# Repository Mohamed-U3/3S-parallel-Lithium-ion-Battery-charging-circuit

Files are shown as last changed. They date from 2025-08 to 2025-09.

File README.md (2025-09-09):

# U3 LiPo Charging Circuit

A complete modular LiPo battery management solution, designed in KiCad by Eng. Mohamed Yousry. This project combines a charger, protection circuit, and active balancer for safe and efficient LiPo battery management, suited for embedded systems, robotics, and DIY electronics.

***

## Features

- **Battery Charging Circuit**
    - **IC:** BQ24090DGQ
    - Input: 5V (USB or external)
    - Integrated current setting, termination, and charging indicators
    - Optimized for single-cell LiPo batteries
- **Battery Protection Circuit**
    - **IC:** XB8889D
    - Overcharge, overdischarge, and short-circuit protection
    - Automatic recovery feature
    - Output and input connectors included for seamless integration
- **Active Balancer Circuit**
    - Balance two battery cells using autonomous active balancer ICs
    - **Inductor-based charge redistribution** for improved battery health
    - Independent status and enable pins for customization

***

## Schematic Overview

The project schematic is divided into three main sections:

1. **Battery Charging Circuit** – Handles safe charging of the LiPo cell.
2. **Battery Protection Circuit** – Protects against voltage and current faults.
3. **Active Balancer Circuit** – Maintains consistent voltage across multi-cell packs.

_All schematic design is done in KiCad 6.0 and up._

***

## Getting Started

### Prerequisites

- **KiCad** version 6.0+ (required to open Design Files)
- Basic electronics assembly and soldering skills

### Files Included

- `LiPoCharger.kicad_sch`: Complete project schematic
- (You may add: BOM, Gerber files, and 3D models if available)

### How to Use

1. **Review the schematic file** (`.kicad_sch`) in KiCad.
2. Modify component values as needed for your specific battery and current specs.
3. Generate PCB layout and fabricate your board.
4. Solder components according to schematic.
5. Integrate into your battery-powered project.

***

## Block Diagram

```
[5V Charger Input] --> [Charging Circuit] --> [Protection Circuit] --> [Active Balancer] --> [Battery Pack]
```

***

## License

This project is open-source and licensed under the MIT License. See `LICENSE` file for details.

***

## Author

**Eng. Mohamed Yousry**
Mechatronics Engineer / Embedded Hardware \& Software Designer

***

## Contribution \& Support

- Issues and pull requests are welcome!
- For questions or collaboration: mohamed.yousry0023@gmail.com

***

## Acknowledgements

- Designed using KiCad EDA 9.0.3
- Inspired by robust battery management requirements in embedded applications
- Inspired by GreatScott! Youtube channel

***

> **Disclaimer:** Double-check all component ratings for your specific application. Improper LiPo charging/protection can be dangerous.

---
<span style="display:none">[^1]</span>

<div style="text-align: center">⁂</div>

[^1]: image.jpeg

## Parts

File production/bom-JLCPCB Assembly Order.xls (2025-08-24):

JLCPCB BOM Tool - BOM Matching
BOM name：bom-JLCPCB Assembly Order-JLCPCB Assembly Order.xlsx |  |  | Download Time：2025-08-14 16:01:05 |  |  |  | * Our matching results are updated in real-time, but stock and prices may change. If it's been over 24 hours, please re-match before placing your order.
PCB Assembled Qty：5 |  |  | Est. Total Price：10.3532
Your BOM |  |  |  |  | Matched Parts |  |  |  |  |  |  | Order Information
Top Designator | Bottom Designator | Comment | Footprint | JLCPCB Part # | Matches | Part # | Manufacturer | Footprint | Description | Category | Warning | JLCPCB Part # | Product link | Lib Type | Qty | Source | Total Price ($)
C1,C10,C11,C2,C3,C6,C7 |  | 10uF | 0402 |  | Select by System | CL05A106MQ5NUNC | Samsung Electro-Mechanics | 0402 | 10uF 6.3V X5R ±20% 0402 Multilayer Ceramic Capacitors MLCC - SMD/SMT ROHS | Multilayer Ceramic Capacitors MLCC - SMD/SMT |  | C15525 | https://jlcpcb.com/partdetail/16204-CL05A106MQ5NUNC/C15525 | Basic | 45 | 45 JLCPCB | 0.2655
C4,C8 |  | 1nF | 0402 |  | Select by System | 0402B102K500NT | FH (Guangdong Fenghua Advanced Tech) | 0402 | 1nF 50V X7R ±10% 0402 Multilayer Ceramic Capacitors MLCC - SMD/SMT ROHS | Multilayer Ceramic Capacitors MLCC - SMD/SMT |  | C1523 | https://jlcpcb.com/partdetail/1875-0402B102K500NT/C1523 | Basic | 20 | 20 JLCPCB | 0.022
C5,C9 |  | 10nF | 0402 |  | Select by System | CL05B103KB5NNNC | Samsung Electro-Mechanics | 0402 | 10nF 50V X7R ±10% 0402 Multilayer Ceramic Capacitors MLCC - SMD/SMT ROHS | Multilayer Ceramic Capacitors MLCC - SMD/SMT |  | C15195 | https://jlcpcb.com/partdetail/15869-CL05B103KB5NNNC/C15195 | Basic | 20 | 20 JLCPCB | 0.026
D1,D3,D4 |  | Red | 0603 |  | Select by System | KT-0603R | Hubei KENTO Elec | 0603 | -40℃~+85℃ Red 0603 LED Indication - Discrete ROHS | LED Indication - Discrete |  | C2286 | https://jlcpcb.com/partdetail/Hubei_KENTOElec-KT0603R/C2286 | Basic | 25 | 25 JLCPCB | 0.14
D2 |  | Green | 0603 |  | Select by System | F.0603.00025/P2-0603G1TS2-06T-002 | TUOZHAN | 0603 | -40℃~+85℃ 120° 2.6V~2.9V 230mcd 520nm~525nm Emerald Green 0603 LED Indication - Discrete ROHS | LED Indication - Discrete |  | C7496818 | https://jlcpcb.com/partdetail/C7496818 | Extended | 20 | 20 JLCPCB | 0.062
J1 |  | Battery_conn_in | 插件,P=2mm |  | Unconfirmed | B2B-PH-K-S(LF)(SN) | JST | 插件,P=2mm | -25℃~+85℃ 1 100V 1x2P 2 2A 2P 2mm 4.5mm 5.9mm 6mm Brass K Pin PA66 PH Through Hole Tin UL94V-0 White Plugin,P=2mm Wire To Board Connector ROHS | Wire To Board Connector | 1.Multiple lines in the BOM have been matched to the same part. Please check if the matching is correct. ; | C131337 | https://jlcpcb.com/partdetail/JST-B2B_PH_K_S_LF_SN/C131337 | Extended | 16 | 16 JLCPCB | 0.4896
J2 |  | Battery_conn_out | 插件,P=2mm |  | Unconfirmed | B2B-PH-K-S(LF)(SN) | JST | 插件,P=2mm | -25℃~+85℃ 1 100V 1x2P 2 2A 2P 2mm 4.5mm 5.9mm 6mm Brass K Pin PA66 PH Through Hole Tin UL94V-0 White Plugin,P=2mm Wire To Board Connector ROHS | Wire To Board Connector | 1.Multiple lines in the BOM have been matched to the same part. Please check if the matching is correct. ; | C131337 | https://jlcpcb.com/partdetail/JST-B2B_PH_K_S_LF_SN/C131337 | Extended | 16 | 16 JLCPCB | 0.4896
J3 |  | Charger_conn | 插件,P=2mm |  | Unconfirmed | B2B-PH-K-S(LF)(SN) | JST | 插件,P=2mm | -25℃~+85℃ 1 100V 1x2P 2 2A 2P 2mm 4.5mm 5.9mm 6mm Brass K Pin PA66 PH Through Hole Tin UL94V-0 White Plugin,P=2mm Wire To Board Connector ROHS | Wire To Board Connector | 1.Multiple lines in the BOM have been matched to the same part. Please check if the matching is correct. ; | C131337 | https://jlcpcb.com/partdetail/JST-B2B_PH_K_S_LF_SN/C131337 | Extended | 16 | 16 JLCPCB | 0.4896
J4 |  | Conn_01x04_batteries | 插件,P=2.5mm |  | Select by System | B4B-EH-A(LF)(SN) | JST | 插件,P=2.5mm | -25℃~+85℃ 1 12.5mm 1x4P 2.5mm 250V 3.8mm 3A 4 4P 6mm Brass EH K Pin PA66 Through Hole Tin UL94V-0 White Plugin,P=2.5mm Wire To Board Connector ROHS | Wire To Board Connector |  | C160258 | https://jlcpcb.com/partdetail/JST-B4B_EH_A_LF_SN/C160258 | Extended | 5 | 5 JLCPCB | 0.2545
L1,L2 |  | 1uH | SMD,3x3mm |  | Select by System | SWPA3010S1R0NT | Sunlord | SMD,3x3mm | 1.4A 1.4A 1uH 85mΩ ±30% SMD,3x3mm Power Inductors ROHS | Power Inductors |  | C57625 | https://jlcpcb.com/partdetail/Sunlord-SWPA3010S1R0NT/C57625 | Extended | 14 | 14 JLCPCB | 0.8022
R1,R6 |  | 1k | 0201 |  | Select by System | 0201WMF1001TEE | UNI-ROYAL(Uniroyal Elec) | 0201 | -55℃~+155℃ 1kΩ 25V 50mW Thick Film Resistor ±1% ±200ppm/℃ 0201 Chip Resistor - Surface Mount ROHS | Chip Resistor - Surface Mount |  | C270365 | https://jlcpcb.com/partdetail/259895-0201WMF1001TEE/C270365 | Extended | 22 | 22 JLCPCB | 0.0132
R2 |  | 536R | 0201 |  | Select by System | RTT015360FTH | RALEC | 0201 | -55℃~+125℃ 25V 50mW 536Ω Thick Film Resistor ±1% ±200ppm/℃ 0201 Chip Resistor - Surface Mount ROHS | Chip Resistor - Surface Mount |  | C166162 | https://jlcpcb.com/partdetail/RALEC-RTT015360FTH/C166162 | Extended | 20 | 20 JLCPCB | 0.042
R3 |  | 10k | 0201 |  | Select by System | 0201WMF1002TEE | UNI-ROYAL(Uniroyal Elec) | 0201 | -55℃~+155℃ 10kΩ 25V 50mW Thick Film Resistor ±1% ±200ppm/℃ 0201 Chip Resistor - Surface Mount ROHS | Chip Resistor - Surface Mount |  | C473048 | https://jlcpcb.com/partdetail/479818-0201WMF1002TEE/C473048 | Extended | 20 | 20 JLCPCB | 0.012
R4,R5,R7,R9 |  | 1k5 | 0201 |  | Select by System | RC0201FR-071K5L | YAGEO | 0201 | -55℃~+125℃ 1.5kΩ 25V 50mW Thick Film Resistor ±1% ±200ppm/℃ 0201 Chip Resistor - Surface Mount ROHS | Chip Resistor - Surface Mount |  | C155737 | https://jlcpcb.com/partdetail/YAGEO-RC0201FR071K5L/C155737 | Extended | 30 | 30 JLCPCB | 0.024
R10,R8 |  | 51K | 0201 |  | Select by System | 0201WMF5102TEE | UNI-ROYAL(Uniroyal Elec) | 0201 | -55℃~+155℃ 25V 50mW 51kΩ Thick Film Resistor ±1% ±200ppm/℃ 0201 Chip Resistor - Surface Mount ROHS | Chip Resistor - Surface Mount |  | C473471 | https://jlcpcb.com/partdetail/479864-0201WMF5102TEE/C473471 | Extended | 20 | 20 JLCPCB | 0.014
U1 |  | BQ24090DGQ | HVSSOP-10-EP-0.5mm |  | Select by System | BQ24090DGQT | Texas Instruments | HVSSOP-10-EP-0.5mm | 0℃~+125℃ 1 125uA 1A 4.2V 4.45V~6.45V Charging IC Lithium Battery Support Support HVSSOP-10-EP-0.5mm Battery Management ROHS | Battery Management |  | C2879218 | https://jlcpcb.com/partdetail/TexasInstruments-BQ24090DGQT/C2879218 | Extended | 5 | 5 JLCPCB | 3.33
U2 |  | XB8089D | SOIC-8-EP |  | Select by System | XB8089D | XySemi | SOIC-8-EP | -40℃~+85℃ 1 2.5V 4.25V Lithium-ion/Polymer SOIC-8-EP Battery Management ROHS | Battery Management |  | C79928 | https://jlcpcb.com/partdetail/XySemi-XB8089D/C79928 | Extended | 5 | 5 JLCPCB | 0.757
U3,U4 |  | ETA3000 | DFN2x2-8 |  | Select by System | ETA3000D2I | etasolution | DFN2x2-8 | -40℃~+85℃ 2 2A 3.75V~12V Battery Balancing IC Lithium-ion/Polymer DFN2x2-8 Battery Management ROHS | Battery Management |  | C7465544 | https://jlcpcb.com/partdetail/etasolution-ETA3000D2I/C7465544 | Extended | 10 | 10 JLCPCB | 3.12
MOUSE-BITE-2MM-SLOT_2,MOUSE-BITE-2MM-SLOT |  | VAL** |  |  | No matches | No Part Selected

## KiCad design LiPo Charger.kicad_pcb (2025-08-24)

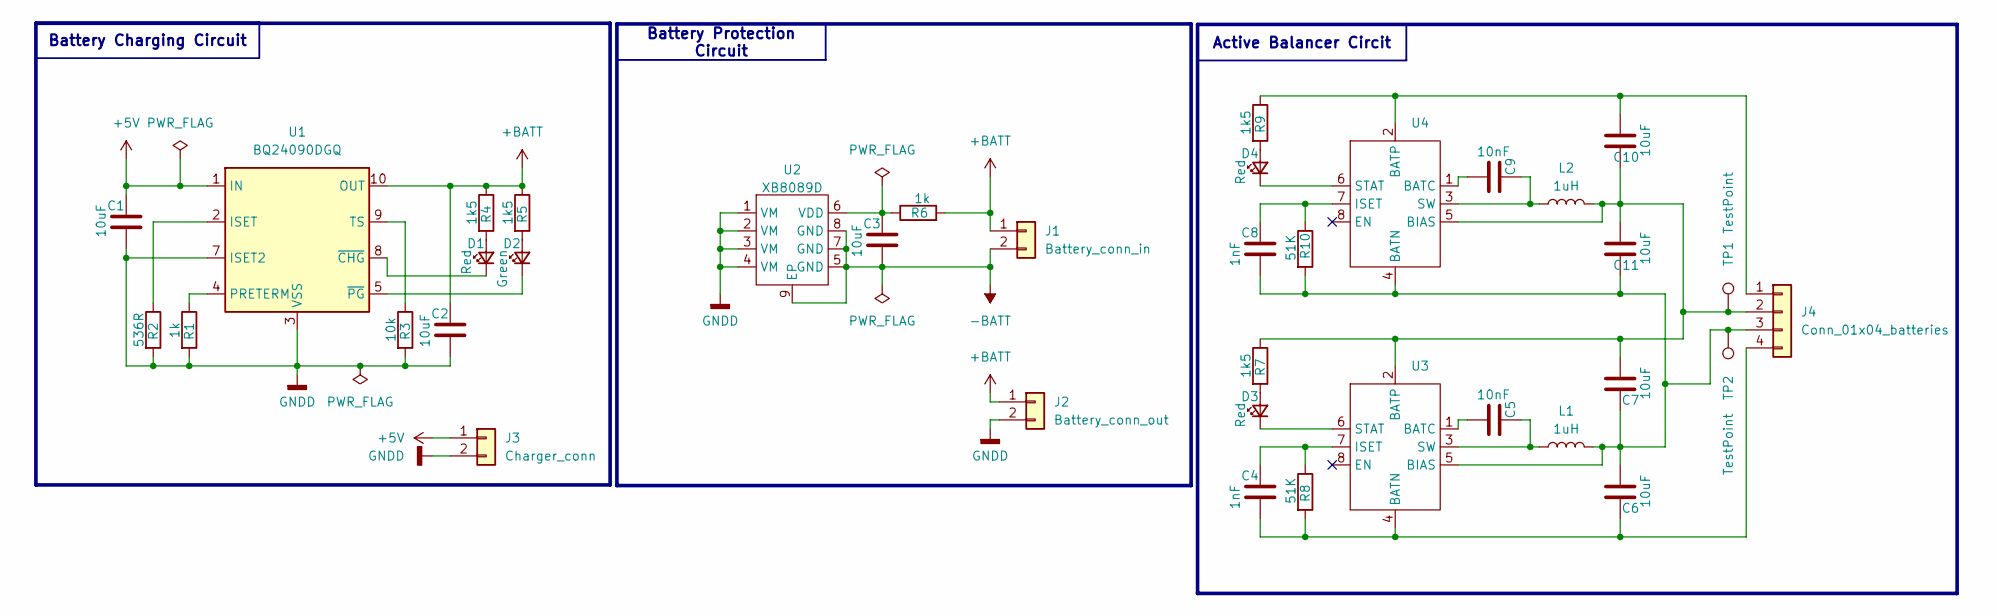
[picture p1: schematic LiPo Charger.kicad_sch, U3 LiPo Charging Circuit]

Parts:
C1, C2, C3, C6, C7, C10, C11: 10uF; C_0402_1005Metric_Pad0.74x0.62mm_HandSolder
C4, C8: 1nF; C_0402_1005Metric_Pad0.74x0.62mm_HandSolder
C5, C9: 10nF; C_0402_1005Metric_Pad0.74x0.62mm_HandSolder
D1, D3, D4: Red; LED_0603_1608Metric_Red
D2: Green; LED_0603_1608Metric_Green
J1: Battery_conn_in; JST_PH_B2B-PH-K_1x02_P2.00mm_Vertical
J2: Battery_conn_out; JST_PH_B2B-PH-K_1x02_P2.00mm_Vertical
J3: Charger_conn; JST_PH_B2B-PH-K_1x02_P2.00mm_Vertical
J4: Conn_01x04_batteries; JST_EH_B4B-EH-A_1x04_P2.50mm_Vertical
L1, L2: 1uH; L_Sunlord_SWPA3010S
R1, R6: 1k; R_0201_0603Metric_Pad0.64x0.40mm_HandSolder
R2: 536R; R_0201_0603Metric_Pad0.64x0.40mm_HandSolder
R3: 10k; R_0201_0603Metric_Pad0.64x0.40mm_HandSolder
R4, R5, R7, R9: 1k5; R_0201_0603Metric_Pad0.64x0.40mm_HandSolder
R8, R10: 51K; R_0201_0603Metric_Pad0.64x0.40mm_HandSolder
TP1, TP2: TestPoint; TestPoint_Pad_D1.5mm
U1: BQ24090DGQ; HVSSOP-10-1EP_3x3mm_P0.5mm_EP1.57x1.88mm_ThermalVias
U2: XB8089D; HTSOP-8-1EP_3.9x4.9mm_P1.27mm_EP2.4x3.2mm_ThermalVias
U3, U4: ETA3000; DFN-8-1EP_2x2mm_P0.5mm_EP0.6x1.2mm

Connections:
+5V: C1.1, J3.1, U1.1 (IN)
+BATT: C2.1, J1.1, J2.1, R4.1, R5.1, R6.2, U1.10 (OUT)
-BATT: C3.2, J1.2, U2.5 (GND), U2.7 (GND), U2.8 (GND), U2.9 (EP)
GNDD: C1.2, C2.2, J2.2, J3.2, R1.2, R2.2, R3.2, U1.3 (VSS), U1.7 (ISET2), U1.11 (VSS), U2.1 (VM), U2.2 (VM), U2.3 (VM), U2.4 (VM)
unnamed: D1.2 (A), R4.2
unnamed: D1.1 (K), U1.8 (~CHG)
unnamed: D2.2 (A), R5.2
unnamed: D2.1 (K), U1.5 (~PG)
unnamed: D3.2 (A), R7.2
unnamed: D3.1 (K), U3.6 (STAT)
unnamed: D4.2 (A), R9.2
unnamed: D4.1 (K), U4.6 (STAT)
unnamed: C10.2, J4.1, R9.1, U4.2 (BATP)
unnamed: C7.2, C10.1, C11.2, J4.2, L2.2, R7.1, TP1.1, U3.2 (BATP), U4.5 (BIAS)
unnamed: C6.2, C7.1, C8.2, C11.1, J4.3, L1.2, R10.2, TP2.1, U3.5 (BIAS), U4.4 (BATN)
unnamed: C4.2, C6.1, J4.4, R8.2, U3.4 (BATN)
unnamed: R2.1, U1.2 (ISET)
unnamed: R1.1, U1.4 (PRETERM)
unnamed: R3.1, U1.9 (TS)
unnamed: C3.1, R6.1, U2.6 (VDD)
unnamed: C5.2, U3.1 (BATC)
unnamed: C4.1, R8.1, U3.7 (ISET)
unnamed: C5.1, L1.1, U3.3 (SW)
unnamed: C9.2, U4.1 (BATC)
unnamed: C8.1, R10.1, U4.7 (ISET)
unnamed: C9.1, L2.1, U4.3 (SW)

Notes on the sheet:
Battery Protection Circuit
Battery Charging Circuit
Active Balancer Circit

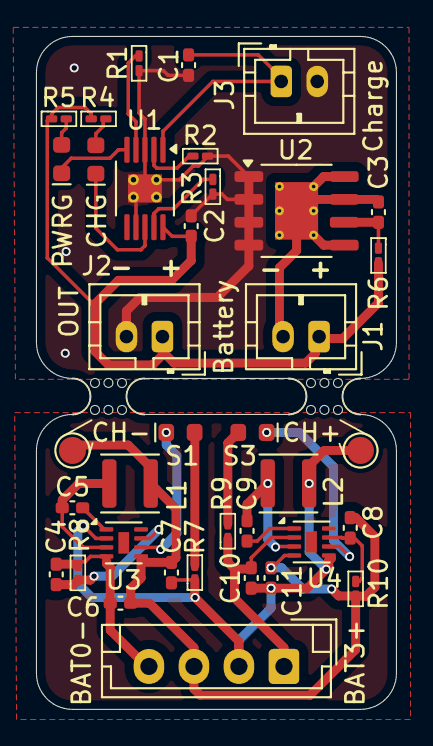
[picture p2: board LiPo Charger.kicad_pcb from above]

Board: 2 copper layers, 20.0 x 37.4 mm, 39 parts (0 on the bottom side), 26 nets.

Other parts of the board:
mouse-bite-2mm-slot, mouse-bite-2mm-slot#2: VAL**; mouse-bite-2mm-slot

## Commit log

2025-08-12 Create .gitignore
    Create .gitignore for Kicad project
2025-08-12 adding v1.0 in the commit, Verion 1.0 is added which has single cell charging and protection circuit. next there will be an active balancer circuit in order for this single charger be able to charge 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
    [LiPo Charger.kicad_pcb, LiPo Charger.kicad_sch]
2025-08-12 feat: battery active balancing is now added.
    [LiPo Charger.kicad_pcb, LiPo Charger.kicad_sch]
2025-08-24 making production files for PCBA.
    [LiPo Charger.kicad_pcb, LiPo Charger.kicad_sch, bom-JLCPCB Assembly Order.xls]
